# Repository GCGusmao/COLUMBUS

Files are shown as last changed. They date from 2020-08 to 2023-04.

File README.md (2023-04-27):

# COLUMBUS

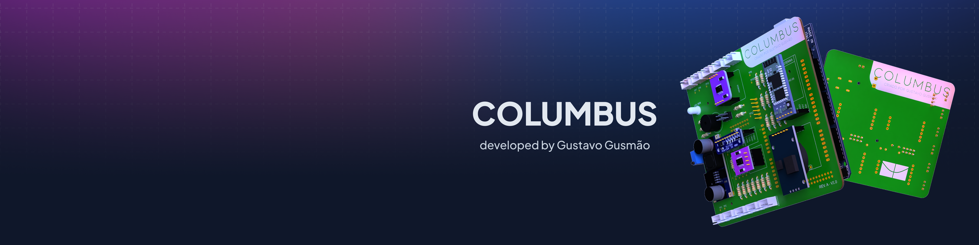
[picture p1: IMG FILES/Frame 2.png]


README ainda em construção.

Desenvolvimento de um sistema de monitoramento para veículos híbridos, baseado em microcontrolador Atmel AVR. Foi desenvolvida a solução completa de hardware, software e soluções mecânicas.

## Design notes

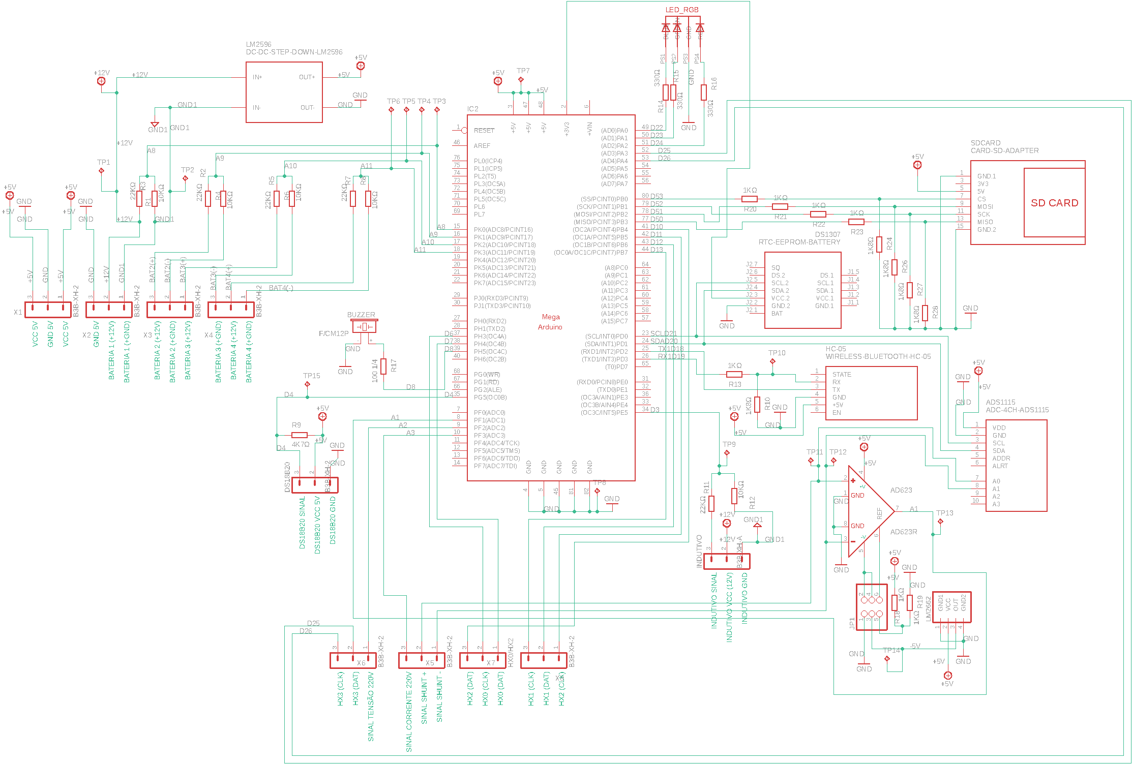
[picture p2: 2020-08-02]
EAGLE FILES/TCC2/Diagrama1.png

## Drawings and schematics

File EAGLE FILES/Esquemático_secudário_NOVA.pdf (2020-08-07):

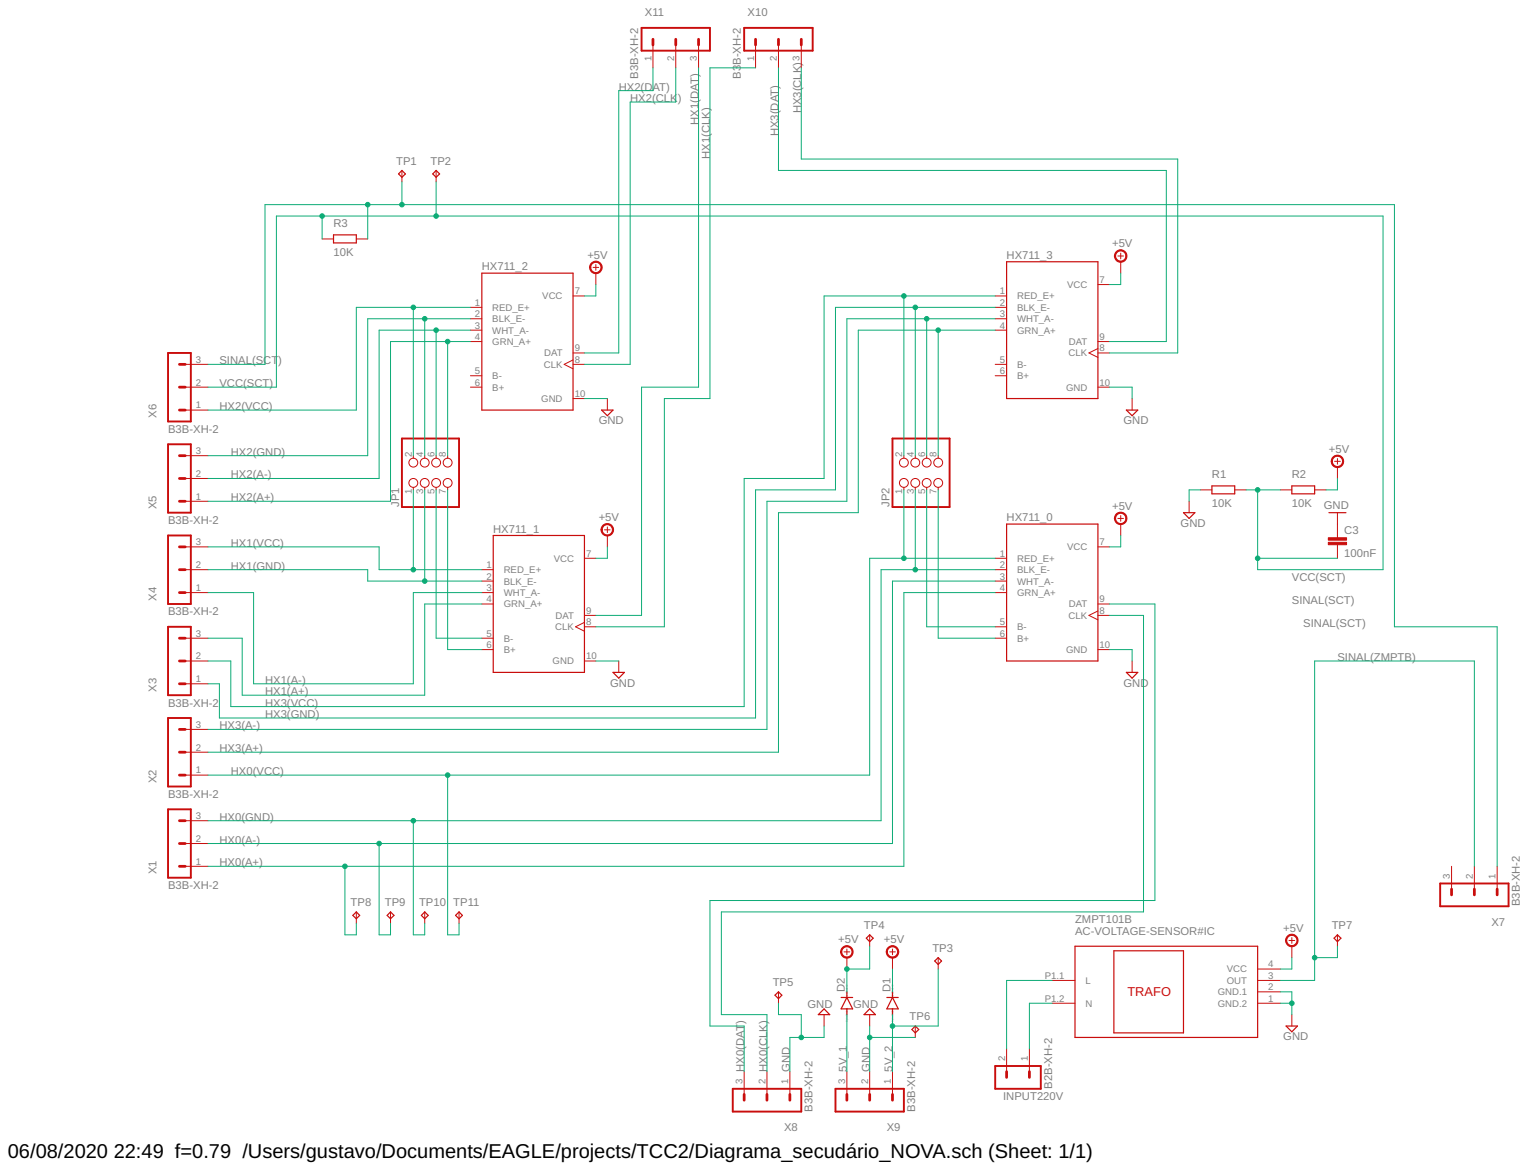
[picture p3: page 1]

VCC(SCT)
SINAL(SCT)

ZMPT101B
AC-VOLTAGE-SENSOR#IC

N | TRAFO | VCC | 4 OUT
P1.2 | L P1.1 | | | 2 GND.2

06/08/2020 22:49 f=0.79 /Users/gustavo/Documents/EAGLE/projects/TCC2/Diagrama_secudário_NOVA.sch (Sheet: 1/1)

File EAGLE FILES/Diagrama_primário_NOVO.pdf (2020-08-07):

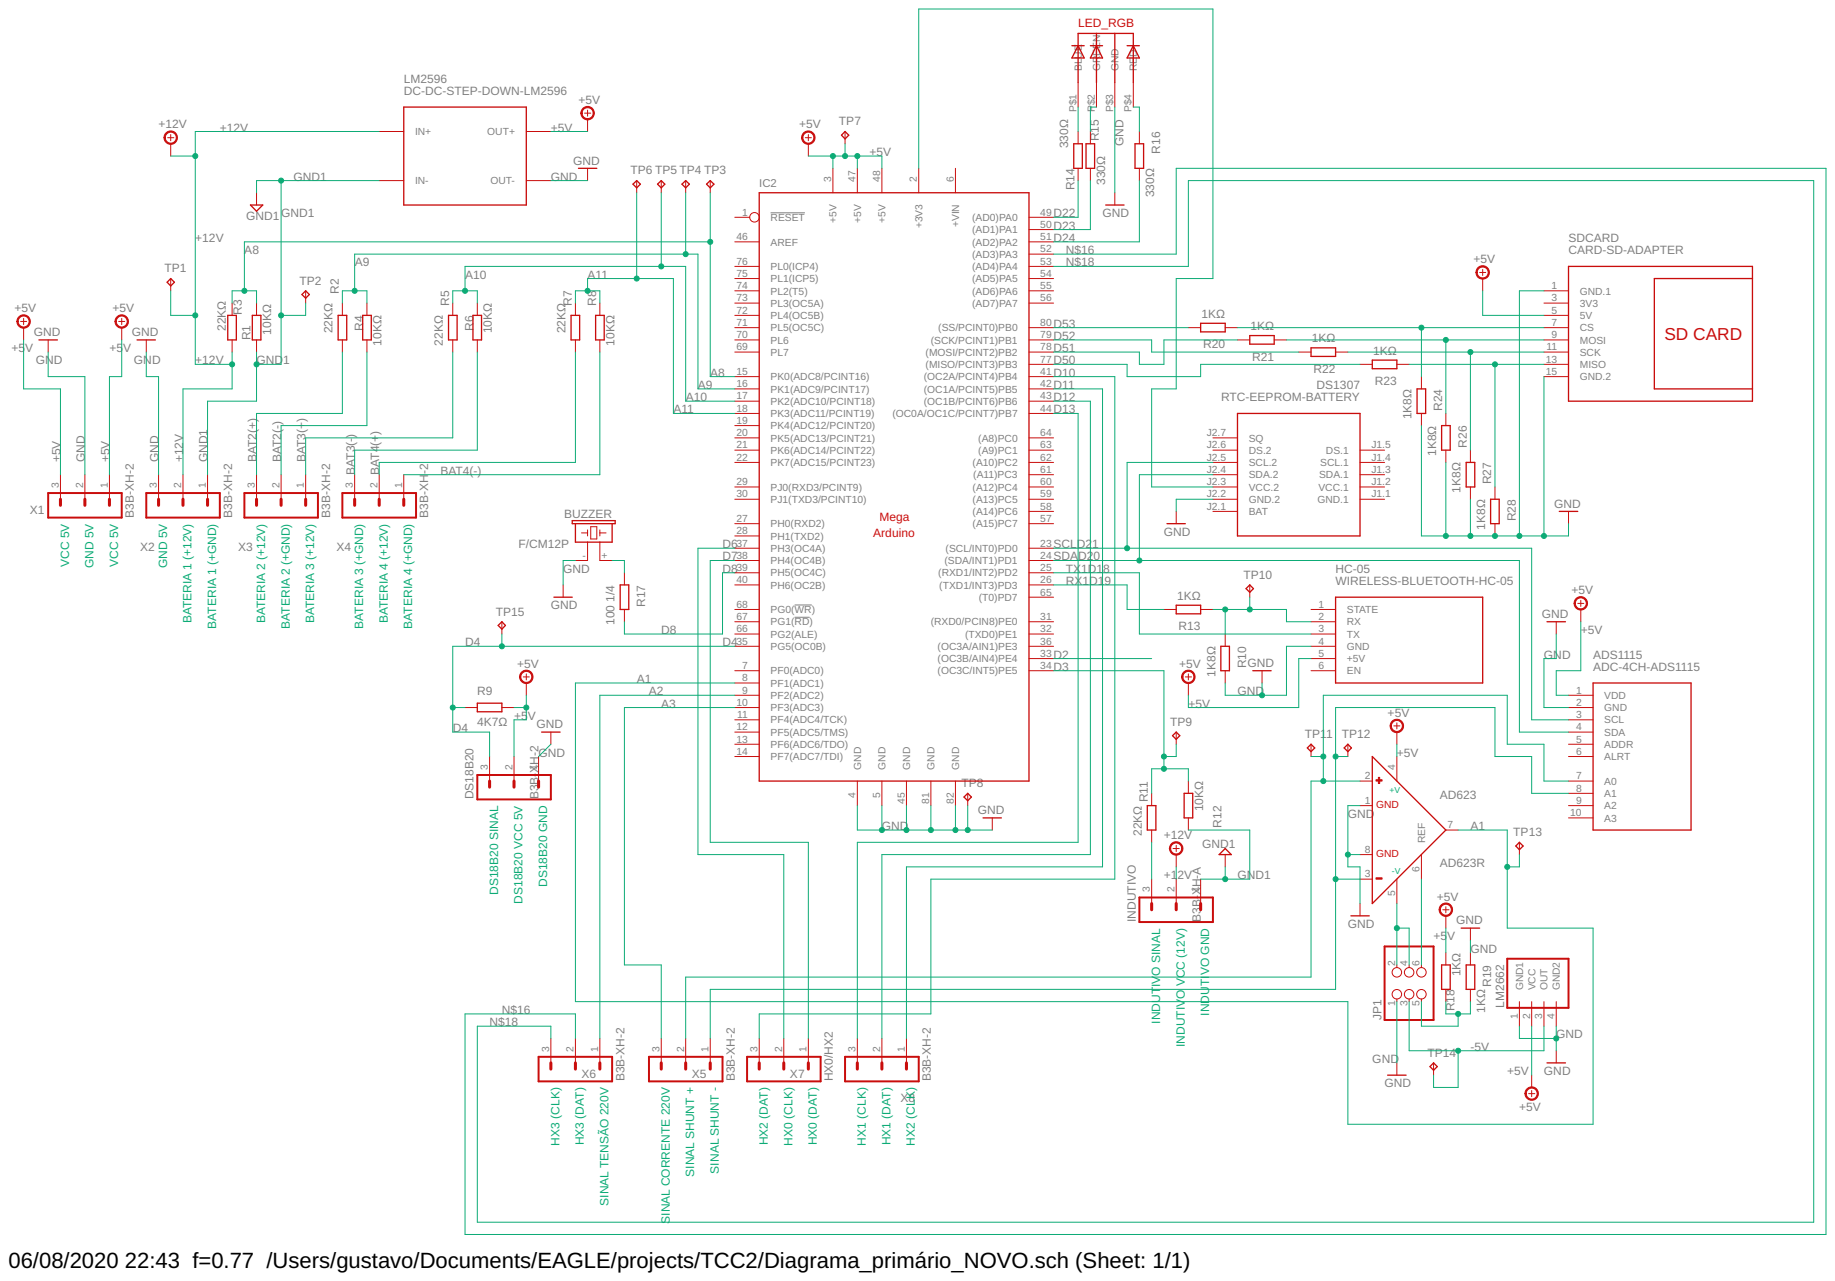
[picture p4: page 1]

DC-DC-STEP-DOWN-LM2596

SDCARD CARD-SD-ADAPTER

BATERIA 1 (+12V) BATERIA 1 (+GND) BATERIA 2 (+12V) BATERIA 2 (+GND) BATERIA 3 (+12V) BATERIA 3 (+GND) BATERIA 4 (+12V) BATERIA 4 (+GND)

24
25 RX1D19 TX1D18 | | HC-05

SINAL SHUNT + SINAL SHUNT -

HX2 (DAT) HX0 (CLK) HX0 (DAT) HX1 (CLK) HX1 (DAT) HX2 (CLK)

06/08/2020 22:43 f=0.77 /Users/gustavo/Documents/EAGLE/projects/TCC2/Diagrama_primário_NOVO.sch (Sheet: 1/1)

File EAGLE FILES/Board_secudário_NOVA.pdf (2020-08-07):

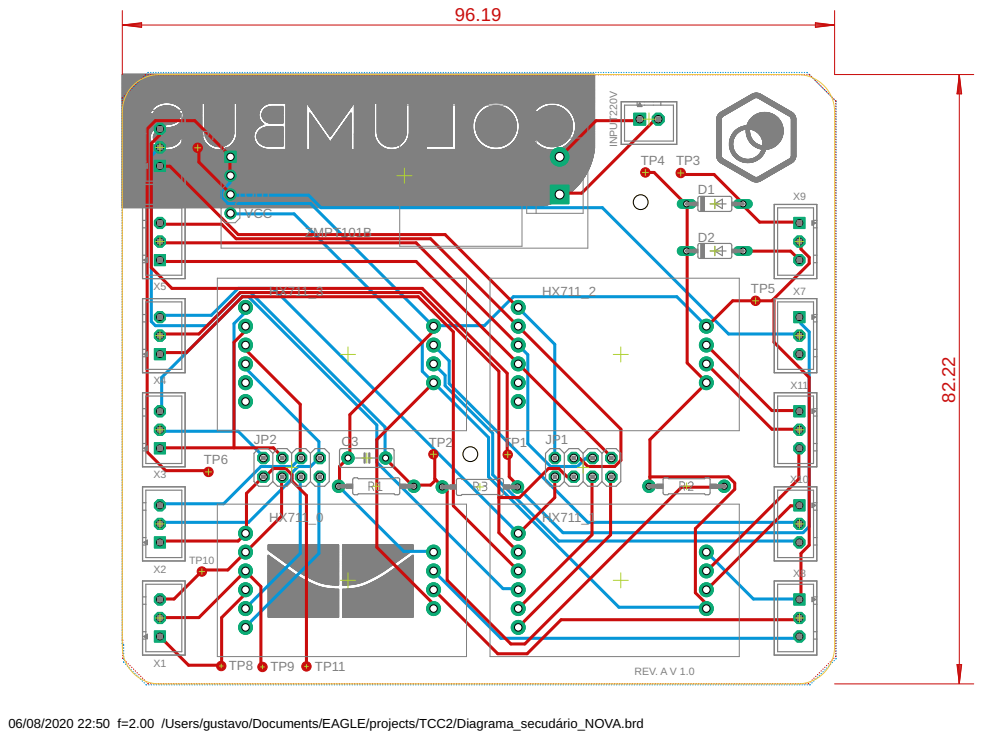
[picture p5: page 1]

06/08/2020 22:50 f=2.00 /Users/gustavo/Documents/EAGLE/projects/TCC2/Diagrama_secudário_NOVA.brd

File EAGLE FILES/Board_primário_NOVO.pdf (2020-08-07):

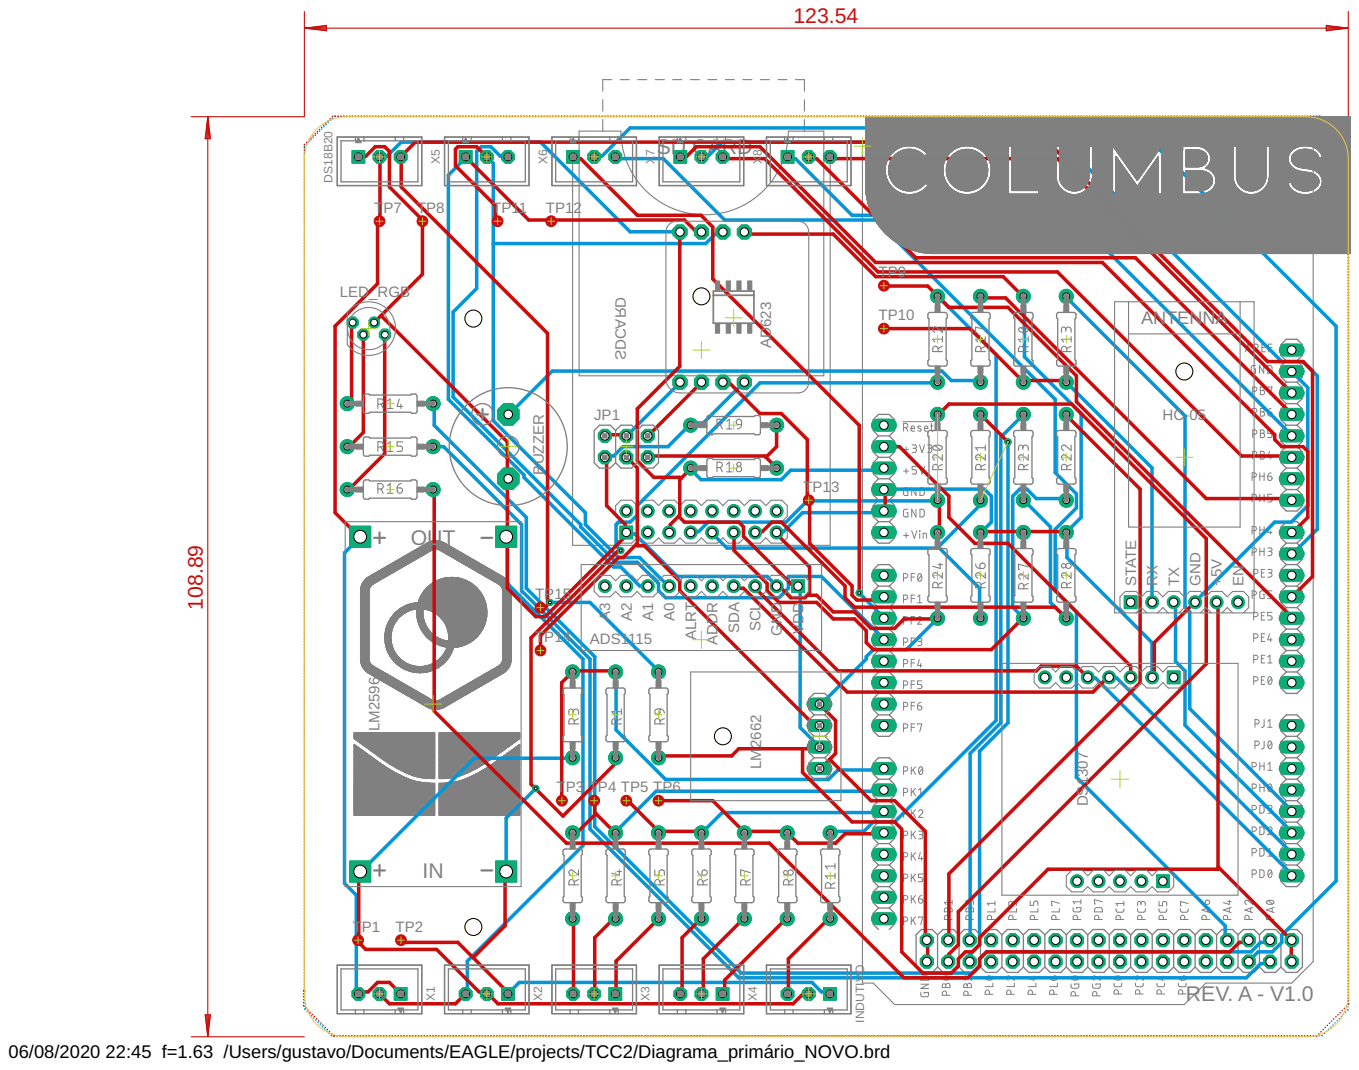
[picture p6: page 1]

06/08/2020 22:45 f=1.63 /Users/gustavo/Documents/EAGLE/projects/TCC2/Diagrama_primário_NOVO.brd

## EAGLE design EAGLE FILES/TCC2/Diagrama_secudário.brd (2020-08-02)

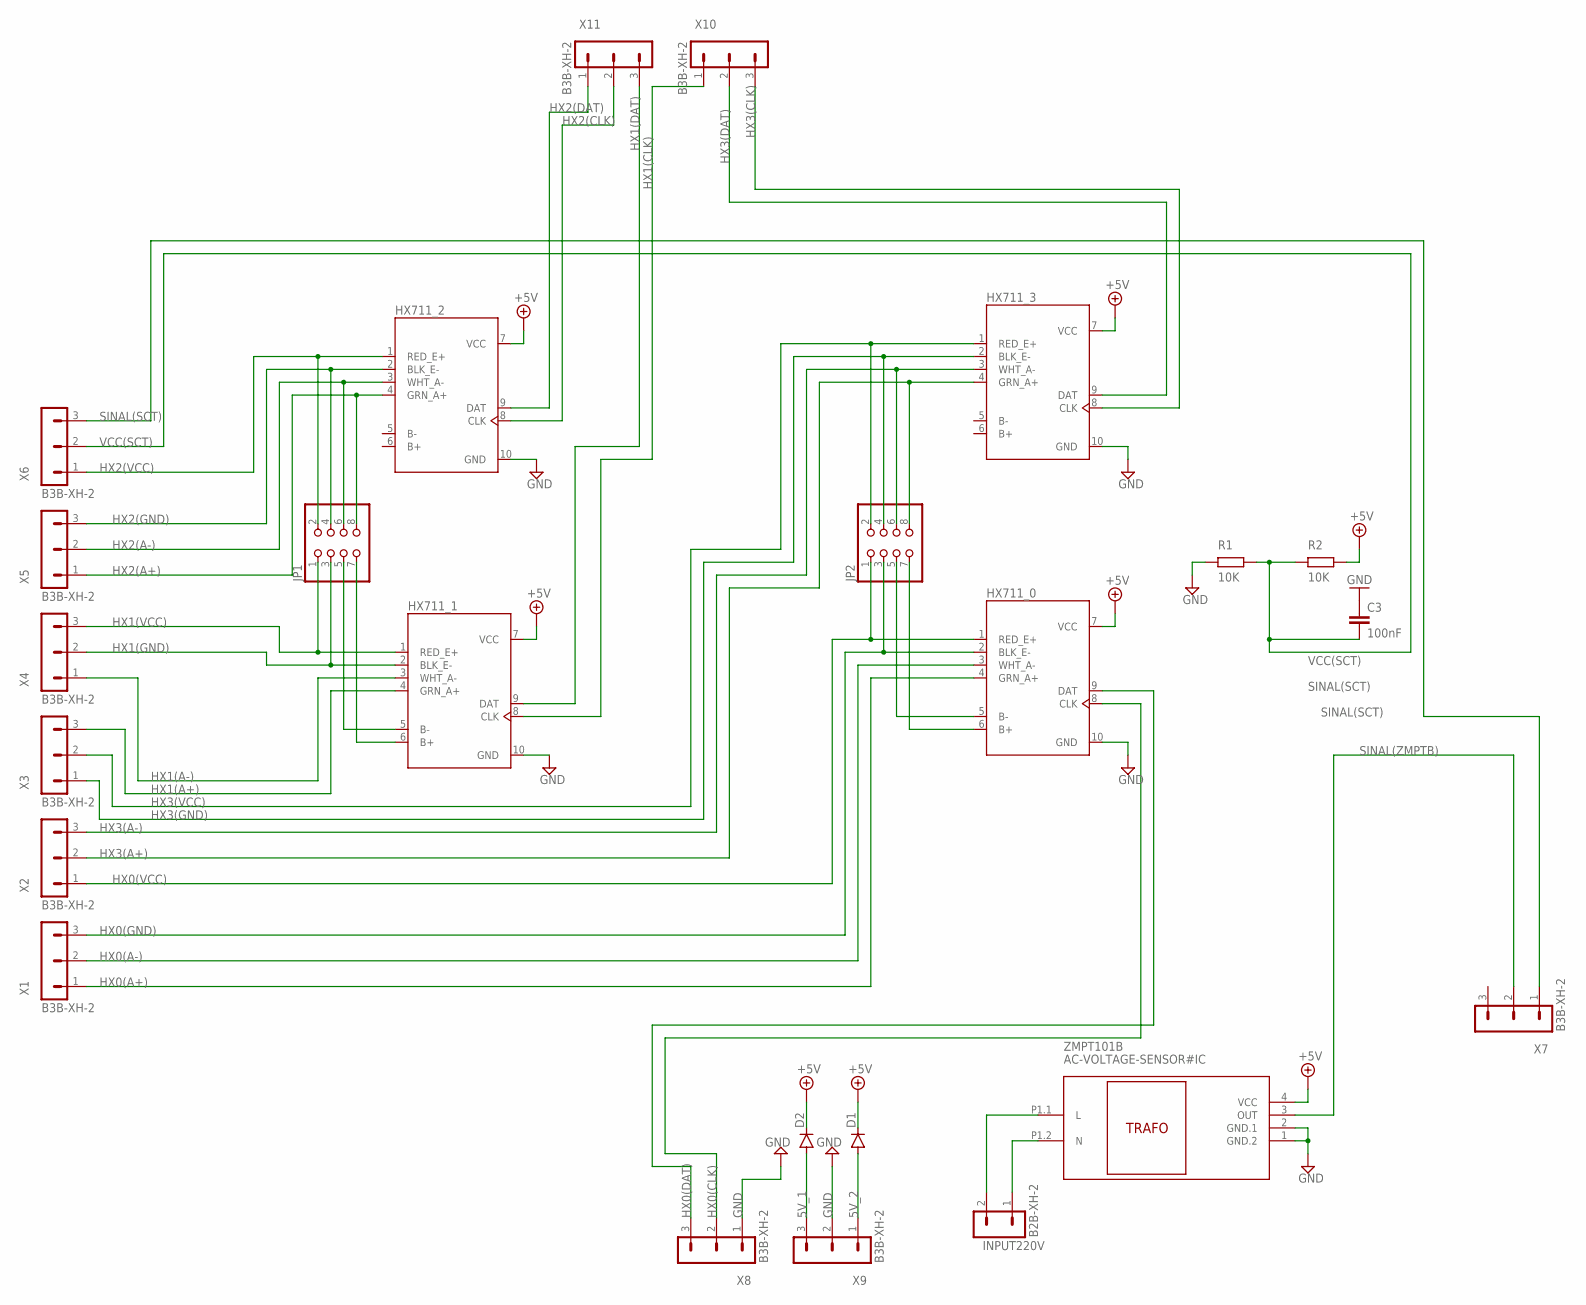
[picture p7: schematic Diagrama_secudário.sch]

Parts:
C3: 100nF; C050-025X075
D1: 1N4148DO35-7; DO35-7
D2: 1; DO35-7
HX711_0, HX711_1, HX711_2, HX711_3: HX711MODULO
INPUT220V: B2B-XH-2; B2B-XH-A
JP1, JP2: PINHD-2X4; 2X04
R1, R2: 10K; 1/4W-0.41K
X1, X2, X3, X4, X5, X6, X7, X8, X9, X10, X11: B3B-XH-2; B3B-XH-A
ZMPT101B: AC-VOLTAGE-SENSOR#IC

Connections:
5V_1: D2.A, X9.3
5V_2: D1.A, X9.1
+5V: D1.C, D2.C, HX711_0.7 (VCC), HX711_1.7 (VCC), HX711_2.7 (VCC), HX711_3.7 (VCC), R2.2, ZMPT101B.4 (VCC)
GND: C3.1, HX711_0.10 (GND), HX711_1.10 (GND), HX711_2.10 (GND), HX711_3.10 (GND), R1.1, X8.1, X9.2, ZMPT101B.1 (GND.2), ZMPT101B.2 (GND.1)
HX0(A+): HX711_0.4 (GRN_A+), X1.1
HX0(A-): HX711_0.3 (WHT_A-), X1.2
HX0(B+): HX711_0.6 (B+), JP2.7
HX0(B-): HX711_0.5 (B-), JP2.5
HX0(CLK): HX711_0.8 (CLK), X8.2
HX0(DAT): HX711_0.9 (DAT), X8.3
HX0(GND): HX711_0.2 (BLK_E-), JP2.3, X1.3
HX0(VCC): HX711_0.1 (RED_E+), JP2.1, X2.1
HX1(A+): HX711_1.4 (GRN_A+), X3.3
HX1(A-): HX711_1.3 (WHT_A-), X4.1
HX1(B+): HX711_1.6 (B+), JP1.7
HX1(B-): HX711_1.5 (B-), JP1.5
HX1(CLK): HX711_1.8 (CLK), X10.1
HX1(DAT): HX711_1.9 (DAT), X11.3
HX1(GND): HX711_1.2 (BLK_E-), JP1.3, X4.2
HX1(VCC): HX711_1.1 (RED_E+), JP1.1, X4.3
HX2(A+): HX711_2.4 (GRN_A+), JP1.8, X5.1
HX2(A-): HX711_2.3 (WHT_A-), JP1.6, X5.2
HX2(CLK): HX711_2.8 (CLK), X11.2
HX2(DAT): HX711_2.9 (DAT), X11.1
HX2(GND): HX711_2.2 (BLK_E-), JP1.4, X5.3
HX2(VCC): HX711_2.1 (RED_E+), JP1.2, X6.1
HX3(A+): HX711_3.4 (GRN_A+), JP2.8, X2.2
HX3(A-): HX711_3.3 (WHT_A-), JP2.6, X2.3
HX3(CLK): HX711_3.8 (CLK), X10.3
HX3(DAT): HX711_3.9 (DAT), X10.2
HX3(GND): HX711_3.2 (BLK_E-), JP2.4, X3.1
HX3(VCC): HX711_3.1 (RED_E+), JP2.2, X3.2
unnamed: INPUT220V.1, ZMPT101B.P1.2 (N)
unnamed: INPUT220V.2, ZMPT101B.P1.1 (L)
SINAL(SCT): X6.3, X7.1
SINAL(ZMPTB): X7.2, ZMPT101B.3 (OUT)
VCC(SCT): C3.2, R1.2, R2.1, X6.2

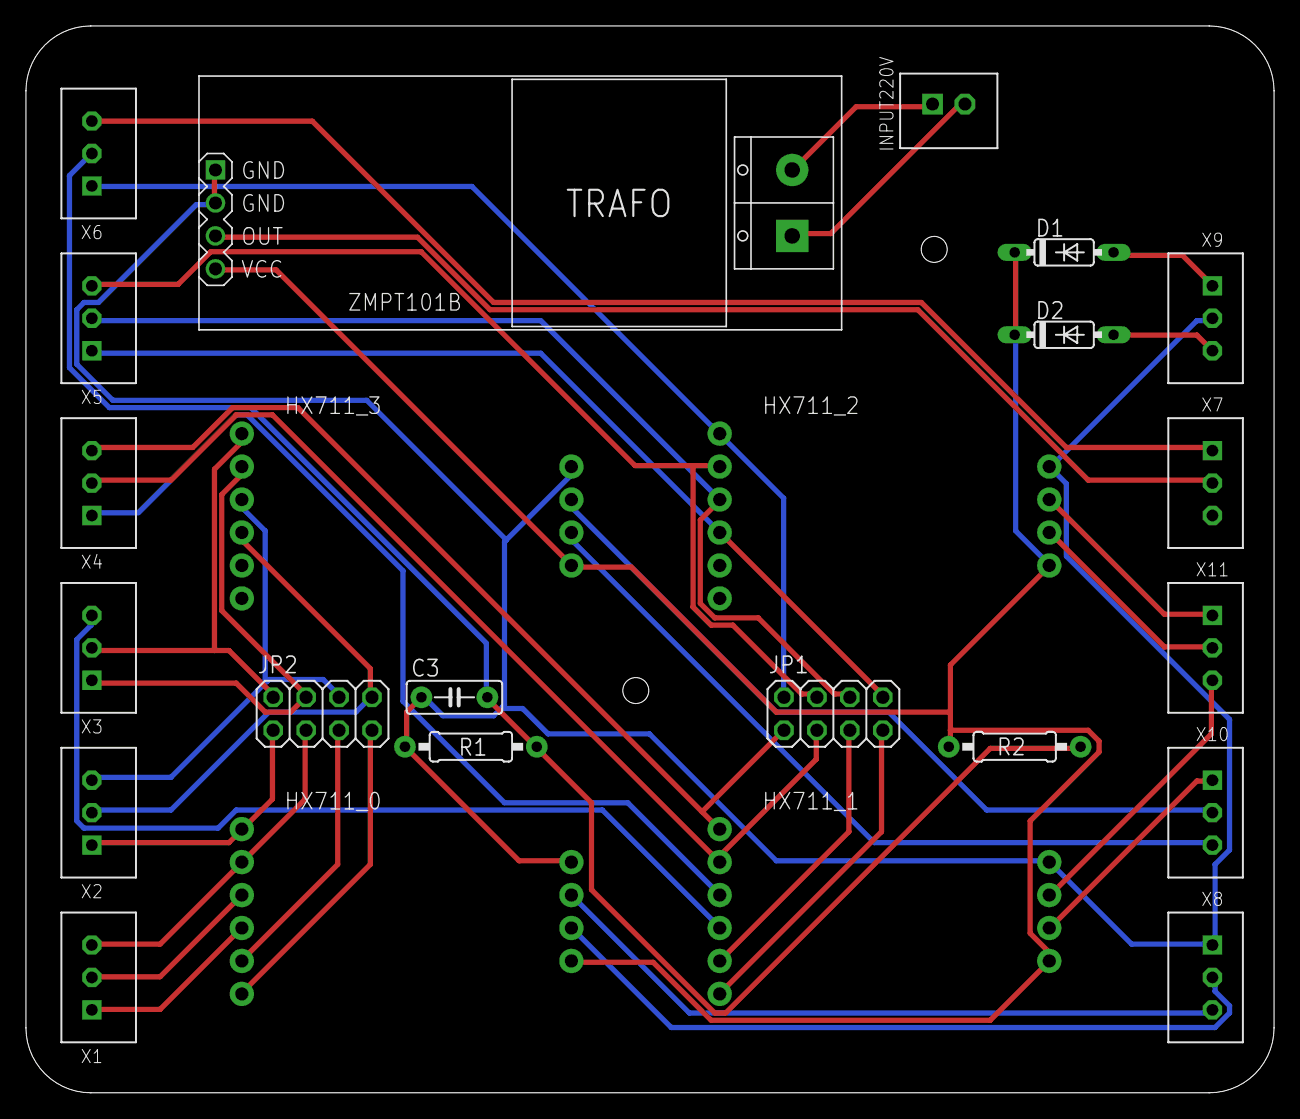
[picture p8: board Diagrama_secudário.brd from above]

Board: 2 copper layers, 96.2 x 82.2 mm, 24 parts (0 on the bottom side), 37 nets.

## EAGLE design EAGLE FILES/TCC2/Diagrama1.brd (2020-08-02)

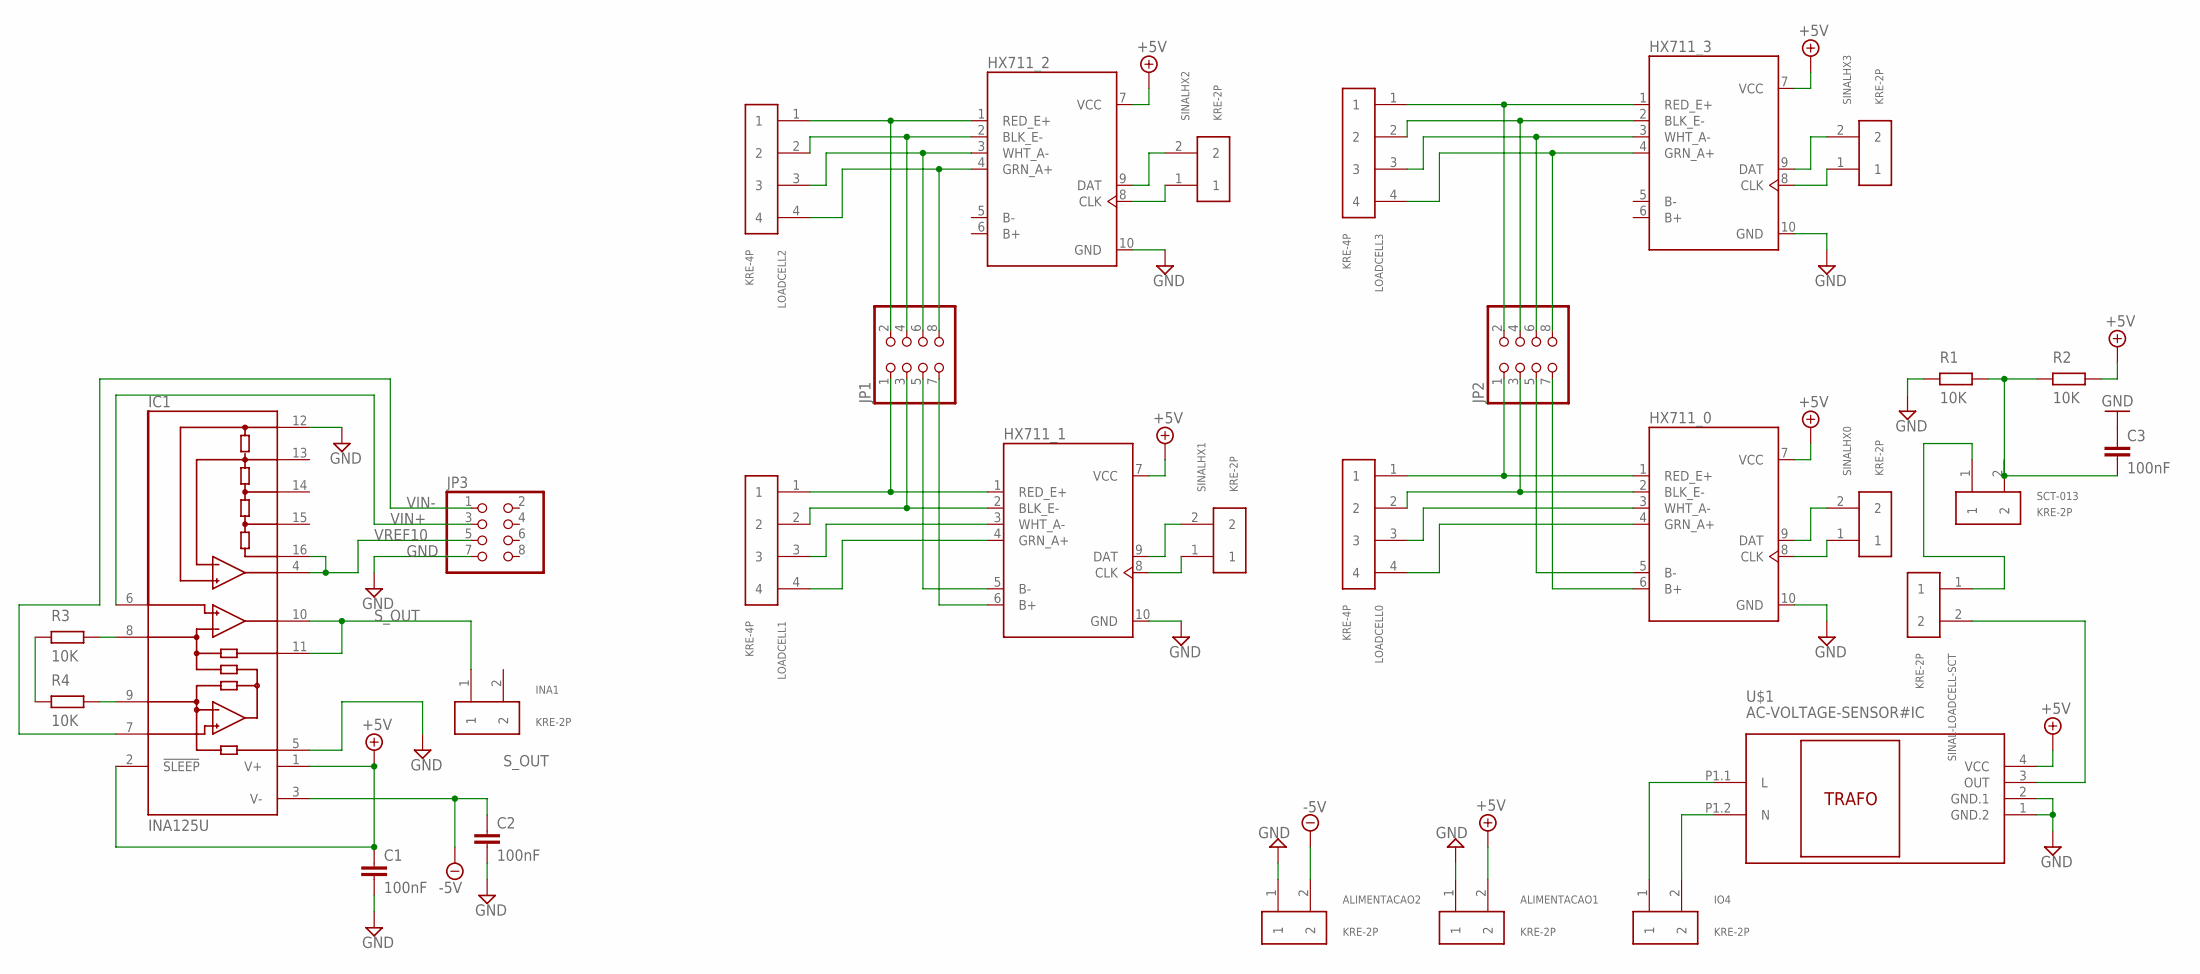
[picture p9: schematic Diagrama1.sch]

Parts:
ALIMENTACAO1, ALIMENTACAO2: KRE-2P
C1, C2, C3: 100nF; C050-025X075
HX711_0, HX711_1, HX711_2, HX711_3: HX711MODULO
IC1: INA125U; SO16-1
INA1: KRE-2P
IO4: KRE-2P
JP1, JP2, JP3: PINHD-2X4; 2X04
LOADCELL0, LOADCELL1, LOADCELL2, LOADCELL3: KRE-4P
R1, R2, R3, R4: 10K; 1/4W-0.41K
SCT-013: KRE-2P
SINAL-LOADCELL-SCT: KRE-2P
SINALHX0, SINALHX1, SINALHX2, SINALHX3: KRE-2P
U$1: AC-VOLTAGE-SENSOR#IC

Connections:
+5V: ALIMENTACAO1.2, C1.1, HX711_0.7 (VCC), HX711_1.7 (VCC), HX711_2.7 (VCC), HX711_3.7 (VCC), IC1.1 (V+), IC1.2 (!SLEEP), R2.2, U$1.4 (VCC)
-5V: ALIMENTACAO2.2, C2.1, IC1.3 (V-)
GND: ALIMENTACAO1.1, ALIMENTACAO2.1, C1.2, C2.2, C3.1, HX711_0.10 (GND), HX711_1.10 (GND), HX711_2.10 (GND), HX711_3.10 (GND), IC1.5 (REF), IC1.12 (REFCOM), JP3.7, R1.1, U$1.1 (GND.2), U$1.2 (GND.1)
unnamed: IO4.2, U$1.P1.2 (N)
unnamed: IO4.1, U$1.P1.1 (L)
unnamed: HX711_0.1 (RED_E+), JP2.1, LOADCELL0.1
unnamed: HX711_0.4 (GRN_A+), LOADCELL0.4
unnamed: HX711_0.2 (BLK_E-), JP2.3, LOADCELL0.2
unnamed: HX711_1.1 (RED_E+), JP1.1, LOADCELL1.1
unnamed: HX711_0.3 (WHT_A-), LOADCELL0.3
unnamed: HX711_1.2 (BLK_E-), JP1.3, LOADCELL1.2
unnamed: HX711_1.3 (WHT_A-), LOADCELL1.3
unnamed: C3.2, R1.2, R2.1, SCT-013.2
unnamed: HX711_0.9 (DAT), SINALHX0.2
unnamed: HX711_0.8 (CLK), SINALHX0.1
unnamed: HX711_1.5 (B-), JP1.5
unnamed: HX711_1.4 (GRN_A+), LOADCELL1.4
unnamed: SINAL-LOADCELL-SCT.2, U$1.3 (OUT)
unnamed: HX711_1.9 (DAT), SINALHX1.2
unnamed: HX711_1.8 (CLK), SINALHX1.1
unnamed: HX711_2.1 (RED_E+), JP1.2, LOADCELL2.1
unnamed: HX711_2.2 (BLK_E-), JP1.4, LOADCELL2.2
unnamed: HX711_2.3 (WHT_A-), JP1.6, LOADCELL2.3
unnamed: HX711_2.4 (GRN_A+), JP1.8, LOADCELL2.4
unnamed: HX711_2.9 (DAT), SINALHX2.2
unnamed: HX711_2.8 (CLK), SINALHX2.1
unnamed: HX711_3.1 (RED_E+), JP2.2, LOADCELL3.1
unnamed: HX711_3.2 (BLK_E-), JP2.4, LOADCELL3.2
unnamed: HX711_3.3 (WHT_A-), JP2.6, LOADCELL3.3
unnamed: HX711_3.4 (GRN_A+), JP2.8, LOADCELL3.4
unnamed: HX711_3.9 (DAT), SINALHX3.2
unnamed: HX711_3.8 (CLK), SINALHX3.1
unnamed: SCT-013.1, SINAL-LOADCELL-SCT.1
unnamed: HX711_1.6 (B+), JP1.7
unnamed: HX711_0.5 (B-), JP2.5
unnamed: HX711_0.6 (B+), JP2.7
unnamed: R3.1, R4.1
unnamed: IC1.9 (RG), R4.2
unnamed: IC1.8 (RG), R3.2
S_OUT: IC1.10 (OUT), IC1.11 (SENSE), INA1.1
VIN+: IC1.6 (+IN), JP3.3
VIN-: IC1.7 (-IN), JP3.1
VREF10: IC1.4 (REFOUT), IC1.16 (REF10), JP3.5

Board: 2 copper layers, 30 parts (0 on the bottom side), 43 nets, no tracks yet.

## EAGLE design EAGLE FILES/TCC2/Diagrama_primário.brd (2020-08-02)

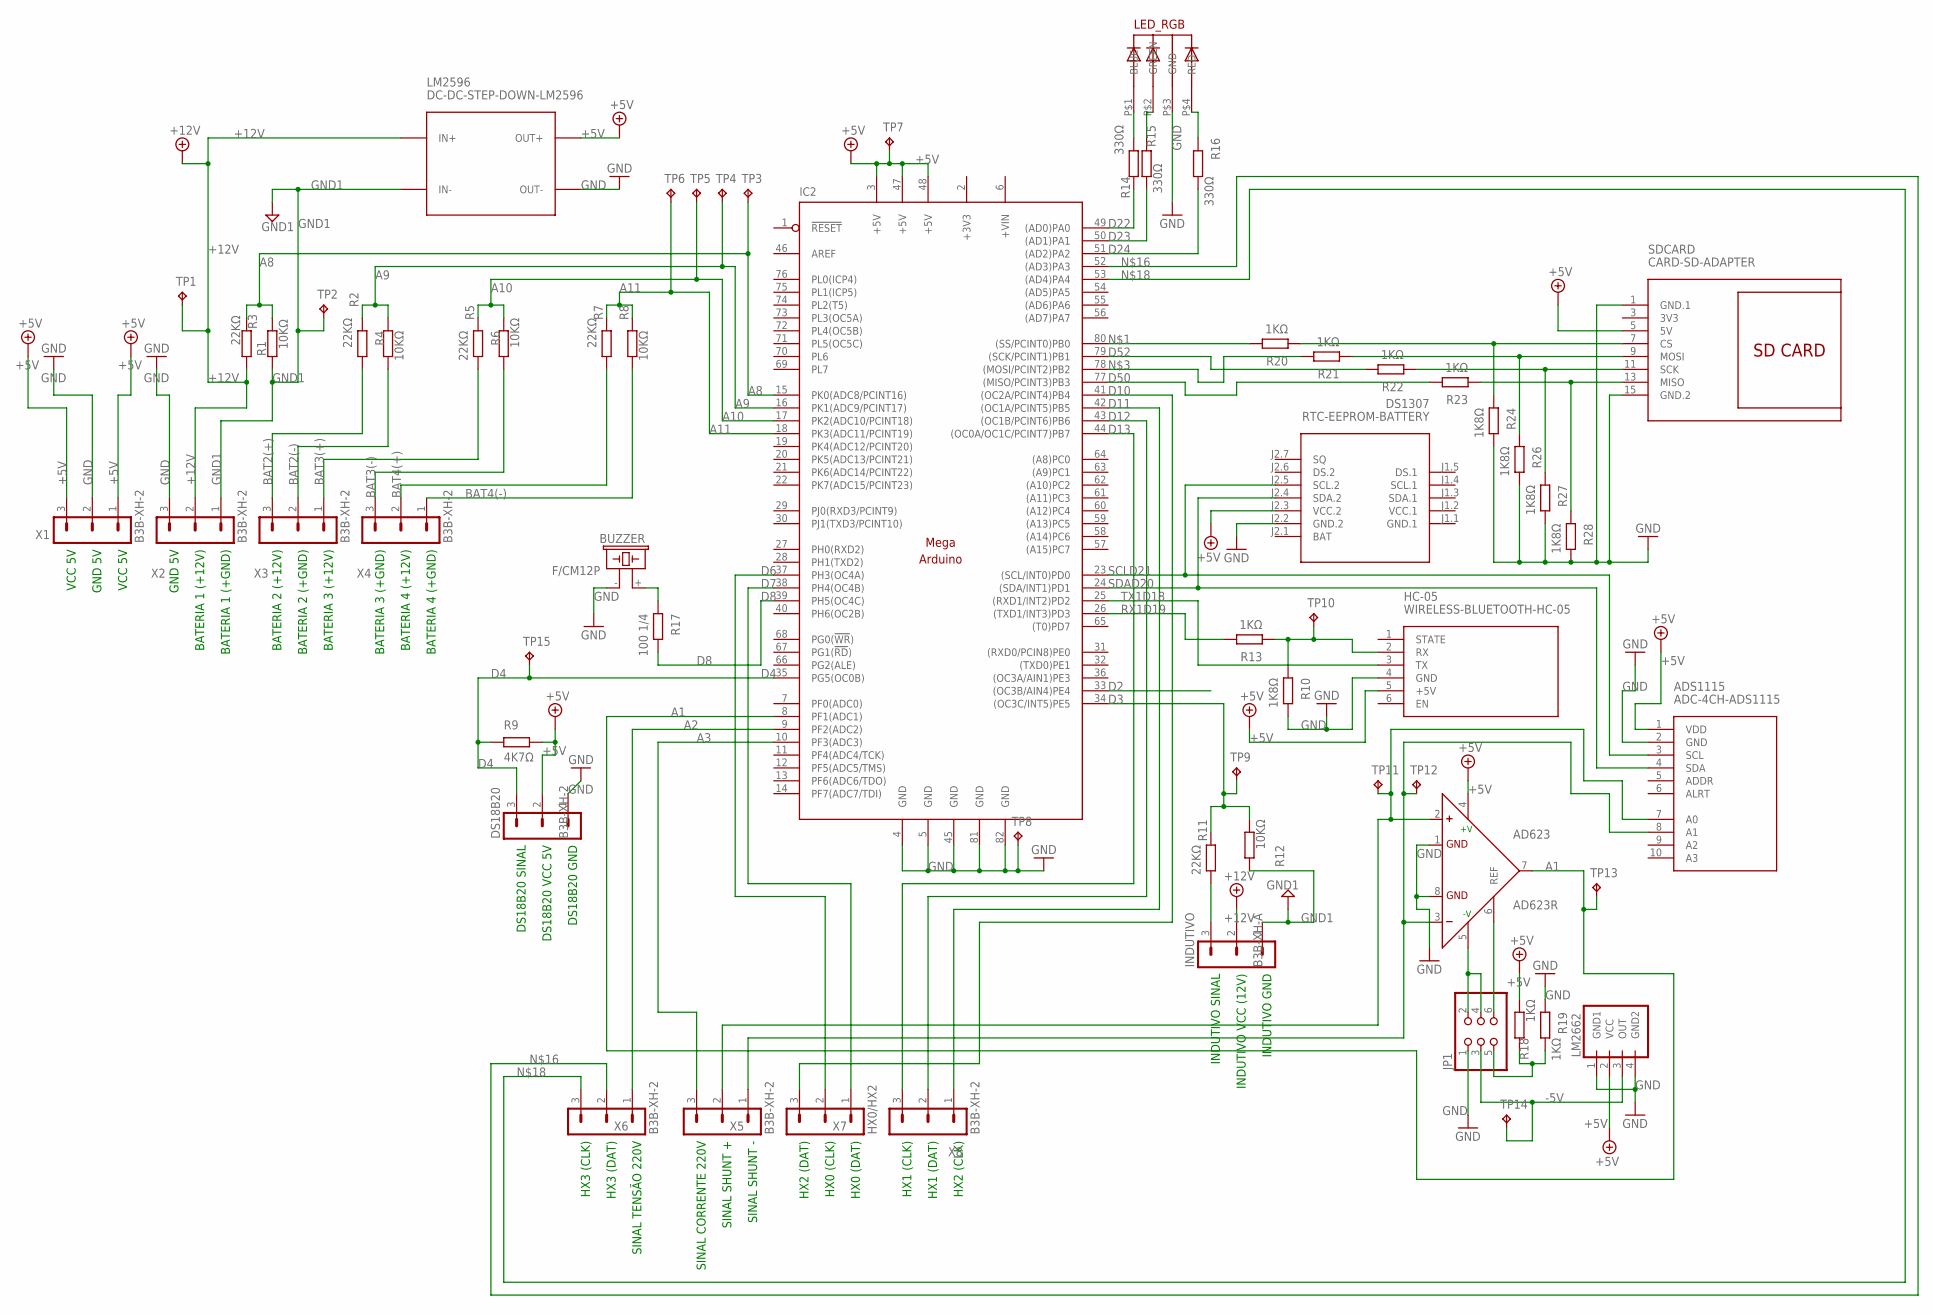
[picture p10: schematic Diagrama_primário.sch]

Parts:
AD623: AD623R; SO8
ADS1115: ADC-4CH-ADS1115
BUZZER: F/CM12P
DS18B20: B3B-XH-2; B3B-XH-A
DS1307: RTC-EEPROM-BATTERY
HC-05: WIRELESS-BLUETOOTH-HC-05
IC2: MEGAARDUINO_11; MEGA_ARDUINO_1
INDUTIVO: B3B-XH-A
JP1: PINHD-2X3; 2X03
LED_RGB: 5MMRGBLED; LED5MMRGB
LM2596: DC-DC-STEP-DOWN-LM2596
LM2662: LM2662
R1, R4, R6, R8, R12: 10KΩ; 1/4W-0.41K
R2, R3, R5, R7, R11: 22KΩ; 1/4W-0.41K
R9: 4K7Ω; 1/4W-0.41K
R10, R24, R26, R27, R28: 1K8Ω; 1/4W-0.41K
R13, R18, R19, R20, R21, R22, R23: 1KΩ; 1/4W-0.41K
R14, R15, R16: 330Ω; 1/4W-0.41K
R17: 100 1/4; 1/4W-0.41K
SDCARD: CARD-SD-ADAPTER
TP1, TP2, TP3, TP4, TP5, TP6, TP7, TP8, TP9, TP10, TP11, TP12, TP13, TP14, TP15: TPB1,27; B1,27
X1, X2, X3, X4, X5, X6, X8: B3B-XH-2; B3B-XH-A
X7: HX0/HX2; B3B-XH-A

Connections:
3V3: SDCARD.3 (3V3)
+3V3: IC2.2 (+3V3)
+5V: AD623.4 (+V), ADS1115.1 (VDD), DS18B20.2, DS1307.J2.3 (VCC.2), HC-05.5 (+5V), IC2.3 (+5V), IC2.47 (+5V), IC2.48 (+5V), LM2596.OUT+, LM2662.2 (VCC), R9.2, R18.1, SDCARD.5 (5V), TP7.TP, X1.1, X1.3
+12V: INDUTIVO.2, LM2596.IN+, R3.2, TP1.TP, X2.2
+VIN: IC2.6 (+VIN)
-5V: JP1.3, LM2662.3 (OUT), TP14.TP
A1: AD623.7 (OUT), IC2.8 (PF1(ADC1)), TP13.TP
A2: IC2.9 (PF2(ADC2)), X6.1
A3: IC2.10 (PF3(ADC3)), X5.3
A8: IC2.15 (PK0(ADC8/PCINT16)), R1.1, R3.1, TP3.TP
A9: IC2.16 (PK1(ADC9/PCINT17)), R2.1, R4.1, TP4.TP
A10: IC2.17 (PK2(ADC10/PCINT18)), R5.1, R6.1, TP5.TP
A11: IC2.18 (PK3(ADC11/PCINT19)), R7.1, R8.1, TP6.TP
BAT2(+): R2.2, X3.3
BAT2(-): R4.2, X3.2
BAT3(+): R5.2, X3.1
BAT3(-): R6.2, X4.3
BAT4(+): R7.2, X4.2
BAT4(-): R8.2, X4.1
D2: IC2.33 ((OC3B/AIN4)PE4)
D3: IC2.34 ((OC3C/INT5)PE5), R11.1, R12.1, TP9.TP
D4: DS18B20.3, IC2.35 (PG5(OC0B)), R9.1, TP15.TP
D6: IC2.37 (PH3(OC4A)), X7.2
D7: IC2.38 (PH4(OC4B)), X7.1
D8: IC2.39 (PH5(OC4C)), R17.2
D10: IC2.41 ((OC2A/PCINT4)PB4), X7.3
D11: IC2.42 ((OC1A/PCINT5)PB5), X8.1
D12: IC2.43 ((OC1B/PCINT6)PB6), X8.2
D13: IC2.44 ((OC0A/OC1C/PCINT7)PB7), X8.3
D22: IC2.49 ((AD0)PA0), R14.2
D23: IC2.50 ((AD1)PA1), R15.2
D24: IC2.51 ((AD2)PA2), R16.2
D50: IC2.77 ((MISO/PCINT3)PB3), R23.2
D51: R21.1, R26.1, SDCARD.9 (MOSI)
D52: IC2.79 ((SCK/PCINT1)PB1), R22.2
D53: R20.1, R24.1, SDCARD.7 (CS)
GND: AD623.1 (RG), AD623.8 (RG), ADS1115.2 (GND), BUZZER.- (2), DS18B20.1, DS1307.J2.2 (GND.2), HC-05.4 (GND), IC2.4 (GND), IC2.5 (GND), IC2.45 (GND), IC2.81 (GND), IC2.82 (GND), JP1.1, LED_RGB.P$3 (GND), LM2596.OUT-, LM2662.1 (GND1), LM2662.4 (GND2), R10.2, R19.1, R24.2, R26.2, R27.2, R28.2, SDCARD.1 (GND.1), SDCARD.15 (GND.2), TP8.TP, X1.2, X2.3
GND1: INDUTIVO.1, LM2596.IN-, R1.2, R12.2, TP2.TP, X2.1
GND.1: DS1307.J1.1 (GND.1)
unnamed: IC2.80 ((SS/PCINT0)PB0), R20.2
unnamed: INDUTIVO.3, R11.2
unnamed: IC2.78 ((MOSI/PCINT2)PB2), R21.2
unnamed: HC-05.2 (RX), R10.1, R13.1, TP10.TP
unnamed: LED_RGB.P$1 (BLUE), R14.1
unnamed: LED_RGB.P$2 (GREEN), R15.1
unnamed: LED_RGB.P$4 (RED), R16.1
unnamed: R22.1, R27.1, SDCARD.11 (SCK)
unnamed: R23.1, R28.1, SDCARD.13 (MISO)
unnamed: IC2.52 ((AD3)PA3), X6.2
unnamed: BUZZER.+ (1), R17.1
unnamed: IC2.53 ((AD4)PA4), X6.3
unnamed: AD623.3 (-), ADS1115.8 (A1), TP12.TP, X5.1
unnamed: AD623.2 (+), ADS1115.7 (A0), TP11.TP, X5.2
unnamed: AD623.5 (-V), JP1.2, JP1.4
unnamed: AD623.6 (REF), JP1.6
RX1D19: IC2.26 ((TXD1/INT3)PD3), R13.2
SCLD21: ADS1115.3 (SCL), DS1307.J2.5 (SCL.2), IC2.23 ((SCL/INT0)PD0)
SDAD20: ADS1115.4 (SDA), DS1307.J2.4 (SDA.2), IC2.24 ((SDA/INT1)PD1)
TX1D18: HC-05.3 (TX), IC2.25 ((RXD1/INT2)PD2)
VCC1: JP1.5, R18.2, R19.2
VCC.1: DS1307.J1.2 (VCC.1)

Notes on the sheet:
SINAL CORRENTE 220V
SINAL SHUNT +
SINAL SHUNT -
HX3 (CLK)
SINAL TENSÃO 220V
HX2 (DAT)
HX0 (CLK)
HX0 (DAT)
HX1 (CLK)
HX1 (DAT)
HX2 (CLK)
INDUTIVO SINAL
INDUTIVO VCC (12V)
INDUTIVO GND
DS18B20 SINAL
DS18B20 VCC 5V
DS18B20 GND
VCC 5V
GND 5V
BATERIA 1 (+12V)
BATERIA 1 (+GND)
BATERIA 2 (+12V)
BATERIA 2 (+GND)
BATERIA 3 (+12V)
BATERIA 3 (+GND)
BATERIA 4 (+12V)
BATERIA 4 (+GND)
HX3 (DAT)

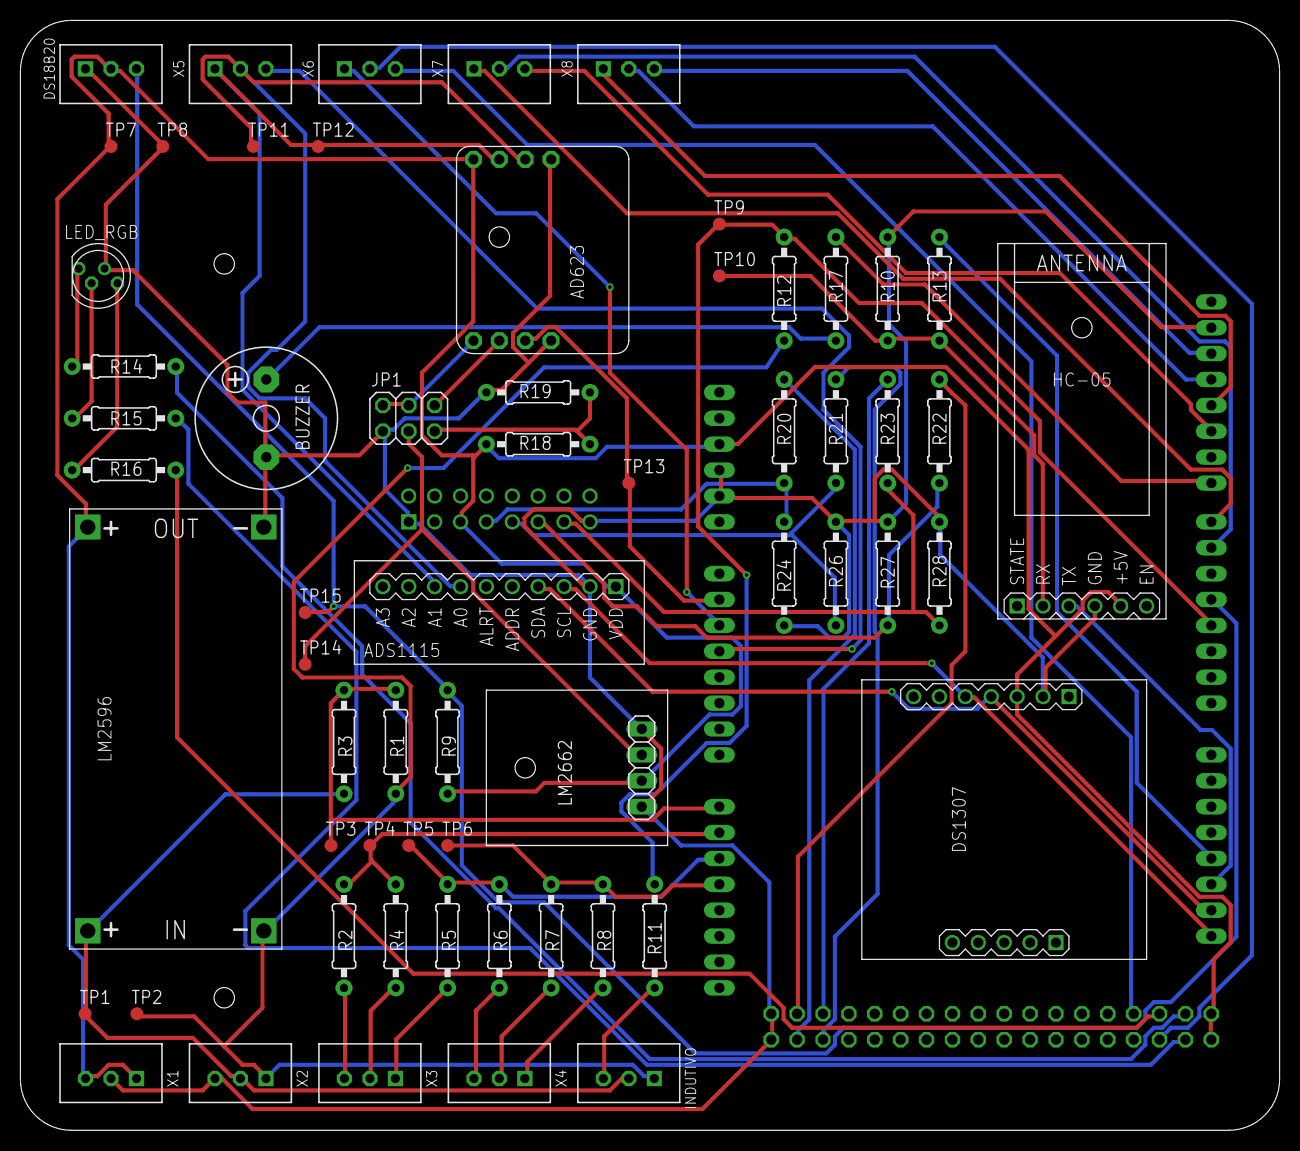
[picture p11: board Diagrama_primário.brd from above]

Board: 2 copper layers, 123.5 x 108.9 mm, 63 parts (0 on the bottom side), 55 nets.

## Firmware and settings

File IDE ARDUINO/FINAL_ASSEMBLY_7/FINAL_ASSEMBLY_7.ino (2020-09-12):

#include <SD.h>
#include <SPI.h>
#include "RTClib.h"
#include "EmonLib.h"
#include <Wire.h>
#include <OneWire.h>
#include <DallasTemperature.h>
#include <Adafruit_ADS1015.h>
#include "HX711.h"                    // Biblioteca HX711 

//define programa do SD CARD
File myFile;

//Módulo RTC DS3231 ligado as portas 20 e 21 do Arduino
RTC_DS3231 rtc;

char daysOfTheWeek[7][12] = {"Sunday", "Monday", "Tuesday", "Wednesday", "Thursday", "Friday", "Saturday"};

//VALOR DE CALIBRAÇÃO PARA SENSOR DE TENSÃO (DEVE SER AJUSTADO EM PARALELO COM UM MULTÍMETRO)
#define VOLT_CAL 400

//VALOR DE AMOSTRAS PARA MÉDIA MÓVEL LEITOR DE TENSÃO 12V
#define AMOSTRAS 10

//Define o pino do sinal digital do DS18B20.
#define ONE_WIRE_BUS 4

#define DOUT_1  7                      // HX711 DATA OUT = pino A0 do Arduino 
#define CLK_1  6                       // HX711 SCK IN = pino A1 do Arduino 

#define DOUT_0  25                      // HX711 DATA OUT = pino A0 do Arduino 
#define CLK_0  26                       // HX711 SCK IN = pino A1 do Arduino 

//Variáveis do LED RGB da placa principal
#define RED_PIN 24
#define GREEN_PIN 23
#define BLUE_PIN 22

//Variáveis relacionadas com o sensor de rotação indutivo
#define pino_D0 3

//Buzzer!

#define NOTE_G4  392
#define NOTE_C5  523

#define REST      0

//Variáveis Buzzer

// change this to make the song slower or faster
int tempo = 85;

// change this to whichever pin you want to use
int buzzer = 8;

int melody[] = {NOTE_C5,8, NOTE_G4,8};

//Mais funções do Buzzer!

int notes = sizeof(melody) / sizeof(melody[0]) / 2;

// this calculates the duration of a whole note in ms
int wholenote = (60000 * 4) / tempo;

int divider = 0, noteDuration = 0;


//Pino analógico conectado ao SCT-013
int pinSCT = A3;

//Cria uma instância para SCT013
EnergyMonitor SCT013;

//CRIA UMA INSTÂNCIA para ZMPT101b (substituir ZMPT por zmpt)
EnergyMonitor ZMPT;

//Módulo ADS1115 com 16-bits
Adafruit_ADS1115 ads;

HX711 balanca_0;                        // define instancia balança HX711
HX711 balanca_1;                        // define instancia balança HX711


// Setup a oneWire instance to communicate with any OneWire device
OneWire oneWire(ONE_WIRE_BUS);

// Pass oneWire reference to DallasTemperature library
DallasTemperature sensors(&oneWire);

// Addresses of 4 DS18B20s
uint8_t sensorX0[8] = { 0x28, 0xAA, 0xB8, 0x5A, 0x4D, 0x14, 0x01, 0x97 };
uint8_t sensorX8[8] = { 0x28, 0xAA, 0x74, 0x9E, 0x4A, 0x14, 0x01, 0xD9 };
uint8_t sensorX4[8] = { 0x28, 0xAA, 0x19, 0xF2, 0x54, 0x14, 0x01, 0x18 };
uint8_t sensorX2[8] = { 0x28, 0xAA, 0x27, 0x04, 0x4D, 0x14, 0x01, 0x82 };

//Variáveis do sensor DS18B20
int deviceCount = 0;
float tempC;
float b1temp;
float b2temp;
float b3temp;
float b4temp;

//Variáveis relacionadas com o sensor de ZMPT101b e SCT013
double tensao250v;
double potencia250v;
double corrente250v;

//Variáveis relacionadas com o sensor de rotação indutivo
int rpm;
int veloc;
volatile byte pulsos;
unsigned long timeold;

//IMPLEMENTACAO EXPERIMENTAL DE VELOCIDADE PELO PULSEIN

double veloc_ON;         //Variável que armazena a leitura INSTANTÂNEA do tempo de injeção.
double veloc_OFF;
int    veloc_PULSE; 

//EXCLUIR O CODIGO ACIMA CASO NAO SEJA UTILIZADO

//Define o número de sinais por volta
unsigned int pulsos_por_volta = 4;

//Pino CS do módulo SD CARD. Pin 53 para Mega / Pin 10 para UNO
int pinoSS = 53;

//Variáveis relacionadas a interface do serial
bool escolha0 = false;

bool escolha1 = false;

//Variável relacionada com o sensor de corrente SHUNT
float correnteLV;

float calibration_factor = 235533.00;     // fator de calibração aferido na Calibraçao

float massa_combustivel;

//Variáveis relacionadas ao medidor de tensão 12V das baterias
float b1tensao;
float b2tensao;
float b3tensao;
float b4tensao;
float btotaltensao;

float aRef = 5.00; //tensão de referência


// constants won't change. They're used here to set pin numbers:
const int buttonPin = 10;  // the number of the pushbutton pin

// variables will change:
int buttonState = 0;         // variable for reading the pushbutton status

bool startState = false; 


//FUNÇÃO LEITURA DE TENSÃO 12V
float lePorta(uint8_t portaAnalogica) {
  float total = 0;
  for (int i = 0; i < AMOSTRAS; i++) {
    total += 1.0 * analogRead(portaAnalogica);
    // delay(5);
  }
  return total / (float)AMOSTRAS;
}


void contador()
{
  //Incrementa contador do sensor de rotação
  pulsos++;
}

void LEDiniciar () {

  digitalWrite(RED_PIN, HIGH);
  digitalWrite(GREEN_PIN, HIGH);
  digitalWrite(BLUE_PIN, HIGH);
  delay(100);
  digitalWrite(RED_PIN, LOW);
  digitalWrite(GREEN_PIN, LOW);
  digitalWrite(BLUE_PIN, HIGH);
  delay(100);
  digitalWrite(RED_PIN, LOW);
  digitalWrite(GREEN_PIN, LOW);
  digitalWrite(BLUE_PIN, LOW);
  delay(100);

}

void LEDerrorON () {
  digitalWrite(RED_PIN, HIGH);
  digitalWrite(GREEN_PIN, LOW);
  digitalWrite(BLUE_PIN, LOW);
}

void LEDerrorOFF () {
  digitalWrite(RED_PIN, LOW);
  digitalWrite(GREEN_PIN, LOW);
  digitalWrite(BLUE_PIN, LOW);
}

void serial0() {

    if (buttonState == HIGH) {
  //COLOCAR AQUI OS SERIAIS DO MODO 1 DE APRESENTACAO DOS DADOS
  //============================================ RTC SERIAL====================================

  DateTime now = rtc.now();

  Serial.print(now.day(), DEC);
  Serial.print('/');
  Serial.print(now.month(), DEC);
  Serial.print('/');
  Serial.print(now.year(), DEC);
  //Serial.print(" (");
  //Serial.print(daysOfTheWeek[now.dayOfTheWeek()]);
  Serial.print(", ");
  Serial.print(now.hour(), DEC);
  Serial.print(':');
  Serial.print(now.minute(), DEC);
  Serial.print(':');
  Serial.print(now.second(), DEC);
  Serial.print(" || ");

  //============================================ ROTAÇÃO SERIAL ====================================

  //Mostra o valor de RPM no serial monitor
  Serial.print("Veloc = ");
  Serial.print(veloc, DEC);
  Serial.print(" || ");
   Serial.print("Veloc+PULSE = ");
  Serial.print(veloc_PULSE, DEC);
  Serial.print(" || ");

  //============================================ CORRENTE LV SERIAL ================================

  Serial.print("Corrente 48V = ");
  Serial.print(correnteLV);
  Serial.print(" || ");

    //=============================================== Tensão 12v ====================

  Serial.print("Tensao B1: ");
  Serial.print(b1tensao, 2);
  Serial.print ("V");
  Serial.print(" || ");

  Serial.print("Tensao B2: ");
  Serial.print(b2tensao, 2);
  Serial.print ("V");
  Serial.print(" || ");

  Serial.print("Tensao B3: ");
  Serial.print(b3tensao, 2);
  Serial.print ("V");
  Serial.print(" || ");

  Serial.print("Tensao B4: ");
  Serial.print(b4tensao, 2);
  Serial.print ("V");
  Serial.print(" || ");

    //============================================= DS18B20 ===================
/*
  Serial.print("Sensor 1: ");
  Serial.print(b1temp);
  Serial.print("C");
  Serial.print(" || ");

  Serial.print("Sensor 2: ");
  Serial.print(b2temp);
  Serial.print("C");
  Serial.println(" || ");

  Serial.print("Sensor 3: ");
  Serial.print(b3temp);
  Serial.print("C");
  Serial.print(" || ");

  Serial.print("Sensor 4: ");
  Serial.print(b4temp);
  Serial.print("C");
  Serial.print(" || ");


  //============================================= CORRENTE, TENSÃO E POTENCIA HV ===================

  Serial.print("Corrente 220V = ");
  Serial.print(corrente250v);
  Serial.print(" A");
  Serial.print(" || ");

  Serial.print("Potencia 220V = ");
  Serial.print(potencia250v);
  Serial.print(" W");
  Serial.print(" || ");

  Serial.print("Tensão 220V = ");
  Serial.print(tensao250v);
  Serial.print(" V");
  Serial.print(" || ");

  //================================================ MASSA COMBUSTIVEL =============================================

  Serial.print("Massa total: ");                            // imprime no monitor serial
  Serial.print(massa_combustivel, 2);              // imprime peso na balança com 2 casas decimais
  Serial.println(" kg");
*/
  //delay(100);
}
}

void serial1() {

    if (buttonState == HIGH) {
  //COLOCAR AQUI OS SERIAIS DO MODO 1 DE APRESENTACAO DOS DADOS
  //============================================ RTC SERIAL====================================

  DateTime now = rtc.now();

  Serial1.print(now.day(), DEC);
  Serial1.print('/');
  Serial1.print(now.month(), DEC);
  Serial1.print('/');
  Serial1.print(now.year(), DEC);
  //Serial.print(" (");
  //Serial.print(daysOfTheWeek[now.dayOfTheWeek()]);
  Serial1.print(", ");
  Serial1.print(now.hour(), DEC);
  Serial1.print(':');
  Serial1.print(now.minute(), DEC);
  Serial1.print(':');
  Serial1.print(now.second(), DEC);
  Serial1.print(" || ");

  //============================================ ROTAÇÃO SERIAL ====================================

  //Mostra o valor de RPM no serial monitor
  Serial1.print("Veloc = ");
  Serial1.print(veloc, DEC);
  Serial1.print(" || ");

  //============================================ CORRENTE LV SERIAL ================================

  Serial1.print("Corrente 48V = ");
  Serial1.print(correnteLV);
  Serial1.print(" || ");

    //=============================================== Tensão 12v ====================

  Serial1.print("Tensao B1: ");
  Serial1.print(b1tensao, 2);
  Serial1.print ("V");
  Serial1.print(" || ");

  Serial1.print("Tensao B2: ");
  Serial1.print(b2tensao, 2);
  Serial1.print ("V");
  Serial1.print(" || ");

  Serial1.print("Tensao B3: ");
  Serial1.print(b3tensao, 2);
  Serial1.print ("V");
  Serial1.print(" || ");

  Serial1.print("Tensao B4: ");
  Serial1.print(b4tensao, 2);
  Serial1.print ("V");
  Serial1.print(" || ");

    //============================================= DS18B20 ===================
/*
  Serial1.print("Sensor 1: ");
  Serial1.print(b1temp);
  Serial1.print("C");
  Serial1.print(" || ");

  Serial1.print("Sensor 2: ");
  Serial1.print(b2temp);
  Serial1.print("C");
  Serial1.print(" || ");

  Serial1.print("Sensor 3: ");
  Serial1.print(b3temp);
  Serial1.print("C");
  Serial1.print(" || ");

  Serial1.print("Sensor 4: ");
  Serial1.print(b4temp);
  Serial1.print("C");
  Serial1.print(" || ");
*/

  //============================================= CORRENTE, TENSÃO E POTENCIA HV ===================
/*
  Serial1.print("Corrente 220V = ");
  Serial1.print(corrente250v);
  Serial1.print(" A");
  Serial1.print(" || ");

  Serial1.print("Potencia 220V = ");
  Serial1.print(potencia250v);
  Serial1.print(" W");
  Serial1.print(" || ");

  Serial1.print("Tensão 220V = ");
  Serial1.print(tensao250v);
  Serial1.print(" V");
  Serial1.print(" || ");
*/
  //================================================ MASSA COMBUSTIVEL =============================================
/*
  Serial1.print("Massa total: ");                            // imprime no monitor serial
  Serial1.print(massa_combustivel, 2);              // imprime peso na balança com 3 casas decimais
  Serial1.println(" kg");
*/
  //delay(100);
}
}

void serialTASK () {

    if (buttonState == HIGH) {
  //=================== SERIAL ===========================
  // Função que solicita o usuário qual forma de apresentação dos dados ele deseja.
  //


  if (Serial1.available()) {
    if (Serial1.read() == '2') {                   // se pressionar 2
      escolha1 = true;
    }
    if (Serial1.read() == '1') {                  // se pressionar 1
      escolha1 = false;
    }
  }
  
  else if (Serial.available()) {
    if (Serial.read() == '2') {                  // se pressionar 2
      escolha0 = true;
    }
    if (Serial.read() == '1') {                  // se pressionar 1
      escolha0 = false;
    }
  }

   if (escolha1 == true)
  {
    serial1();            // Chama a função da escrita no monitor serial Bluetooth
  }
  else if (escolha0 == true)
  {
    serial0();            // Chama a função da escrita no monitor serial USB
  }

    // read the state of the pushbutton value:
  buttonState = digitalRead(buttonPin);


}
}

void gravacaoTask() {

    if (buttonState == HIGH) {
  //=================== SD CARD ===========================

 if (SD.exists("datalog2.csv")) { // Se o Arquivo abrir imprime:

  
  myFile = SD.open("datalog2.csv", FILE_WRITE); // Cria / Abre arquivo .txt



    digitalWrite(RED_PIN, LOW);
    digitalWrite(GREEN_PIN, HIGH);
    digitalWrite(BLUE_PIN, LOW);

    if (escolha0 == true || escolha1 == true)                  // se pressionar t ou T
    {
      Serial.println("Escrevendo no Arquivo .txt"); // Imprime na tela
    }


    DateTime now = rtc.now();

    myFile.print(now.day(), DEC);
    myFile.print('/');
    myFile.print(now.month(), DEC);
    myFile.print('/');
    myFile.print(now.year(), DEC);
    myFile.print(";");
    myFile.print(now.hour(), DEC);
    myFile.print(':');
    myFile.print(now.minute(), DEC);
    myFile.print(':');
    myFile.print(now.second(), DEC);
    myFile.print(";"); // Escreve no Arquivo

    
//========================== ROTAÇÃO ============================
    myFile.print(veloc); // Escreve no Arquivo
    myFile.print(";"); // Escreve no Arquivo
//========================== CORRENTE LV =========================
    myFile.print(correnteLV); // Escreve no Arquivo
    myFile.print(";"); // Escreve no Arquivo
//========================== TENSÃO LV ===========================
    myFile.print(b1tensao); // Escreve no Arquivo
    myFile.print(";"); // Escreve no Arquivo
    myFile.print(b2tensao); // Escreve no Arquivo
    myFile.print(";"); // Escreve no Arquivo
    myFile.print(b3tensao); // Escreve no Arquivo
    myFile.print(";"); // Escreve no Arquivo
    myFile.print(b4tensao); // Escreve no Arquivo
    myFile.print(";"); // Escreve no Arquivo
//========================== CORRENTE HV =========================
    myFile.print(corrente250v); // Escreve no Arquivo
    myFile.print(";"); // Escreve no Arquivo
//========================== TENSÃO HV =========================
    myFile.print(tensao250v); // Escreve no Arquivo
    myFile.print(";"); // Escreve no Arquivo
//========================== TEMPERATURA BATERIAS =================
    myFile.print(b1temp); // Escreve no Arquivo
    myFile.print(";"); // Escreve no Arquivo
    myFile.print(b2temp); // Escreve no Arquivo
    myFile.print(";"); // Escreve no Arquivo
    myFile.print(b3temp); // Escreve no Arquivo
    myFile.print(";"); // Escreve no Arquivo
    myFile.print(b4temp); // Escreve no Arquivo
    myFile.print(";"); // Escreve no Arquivo
//========================== MASSA COMBUSTIVEL =========================
    myFile.println(massa_combustivel); // Escreve no Arquivo
   // myFile.print(","); // Escreve no Arquivo

    digitalWrite(RED_PIN, LOW);
    digitalWrite(GREEN_PIN, LOW);
    digitalWrite(BLUE_PIN, LOW);

    myFile.close(); // Fecha o Arquivo após escrever

    if (escolha0 == true || escolha1 == true)                  // se pressionar t ou T
    {

      Serial.println("Terminado."); // Imprime na tela
      Serial.println(" ");

    }

    digitalWrite(RED_PIN, LOW);
    digitalWrite(GREEN_PIN, HIGH);
    digitalWrite(BLUE_PIN, LOW);


  }

  else {// Se o Arquivo não abrir

    LEDerrorON ();

    if (escolha0 == true || escolha1 == true)                  // se pressionar t ou T
    {

      Serial.println("Erro ao Abrir Arquivo .txt"); // Imprime na tela

    }
    
    delay(1000);

    LEDerrorOFF ();


  }

  /*myFile = SD.open("datalog.txt"); // Abre o Arquivo

    if (myFile) {
    Serial.println("Conteúdo do Arquivo:"); // Imprime na tela

    while (myFile.available()) { // Exibe o conteúdo do Arquivo
    Serial.write(myFile.read());
    }

    myFile.close(); // Fecha o Arquivo após ler
    }

    else {
    Serial.println("Erro ao Abrir Arquivo .txt"); // Imprime na tela
    }
  */
}
}

void aquisicao1TASK() {

    if (buttonState == HIGH) {

//================================== ROTAÇÃO =======================================

  //Atualiza contador a cada segundo
  if (millis() - timeold >= 500)
  {
    //Desabilita interrupcao durante o calculo
    detachInterrupt(1);
    rpm = (60 * 1000 / pulsos_por_volta ) / (millis() - timeold) * pulsos;
    timeold = millis();
    pulsos = 0;
    //Habilita interrupcao
    attachInterrupt(1, contador, FALLING);
  }

  veloc_ON = pulseIn(1, HIGH);
  veloc_OFF = pulseIn(1, LOW);
  
  veloc_PULSE = ((1/((veloc_ON + veloc_OFF)/2000))*750);
    //veloc = ((1/((veloc_ON)/2000))*860) / 2;

//==================================================================================
//**********************************************************************************
//================================== SHUNT =========================================

  int16_t results;

  results = ads.readADC_Differential_0_1();


  correnteLV = ((float)results * 256.0) / 32768.0;//100mv shunt
  correnteLV = correnteLV * 1.333; //uncomment for 75mv shunt *JOGAR ESSES VALORES PARA O TASK DE CALCULO POSTERIORMENTE
  //amps = amps * 2; //uncomment for 50mv shunt

//==================================================================================
//**********************************************************************************
//================================== TENSÃO 12V ====================================

  b1tensao = (lePorta(A8) * aRef) / 1024.0;
  b2tensao = (lePorta(A9) * aRef) / 1024.0;
  b3tensao = (lePorta(A10) * aRef) / 1024.0;
  b4tensao = (lePorta(A11) * aRef) / 1024.0;

//==================================================================================
//**********************************************************************************
//================================== CORRENTE 220V =================================

  corrente250v = SCT013.calcIrms(1380);   // Calcula o valor da Corrente

//==================================================================================
//**********************************************************************************
//================================== TENSÃO 220V ===================================

  ZMPT.calcVI(10, 100); //FUNÇÃO DE CÁLCULO (20 SEMICICLOS, TEMPO LIMITE PARA FAZER A MEDIÇÃO)

  tensao250v = ZMPT.Vrms; //VARIÁVEL RECEBE O VALOR DE TENSÃO RMS OBTIDO

//==================================================================================

}
}


void aquisicao2TASK() {

    if (buttonState == HIGH) {

//================================== TEMPERATURA ===================================

  sensors.requestTemperatures();

  b1temp = sensors.getTempC(sensorX0);
  b2temp = sensors.getTempC(sensorX2);
  b3temp = sensors.getTempC(sensorX4);
  b4temp = sensors.getTempC(sensorX8);

//==================================================================================
//**********************************************************************************
//================================== CÉLULA DE CARGA ===============================

  //Serial.print("Peso 0: ");                            // imprime no monitor serial
  //Serial.print(balanca_0.get_units(), 2);              // imprime peso na balança com 3 casas decimais
  //Serial.print(" kg");                             // imprime no monitor serial
  //delay(500) ;                                       // atraso de 0,5 segundos

  //  Serial.print(" || Peso 1: ");                            // imprime no monitor serial
  //Serial.print(balanca_1.get_units(), 2);              // imprime peso na balança com 3 casas decimais
  //Serial.print(" kg");                             // imprime no monitor serial
  //delay(500) ; 

  if(rpm == 0){
  massa_combustivel = balanca_0.get_units() + balanca_1.get_units();
  }

//==================================================================================
    }
}

void operacoesTASK(){

    if (buttonState == HIGH) {

  b4tensao = (b4tensao * 9.95) - (b3tensao * 7.52);  //fator de calibração para os divisores de tensão.
  b3tensao = (b3tensao * 7.52) - (b2tensao * 4.95);  //fator de calibração para os divisores de tensão.
  b2tensao = (b2tensao * 4.95) - (b1tensao * 2.985);  //fator de calibração para os divisores de tensão.
  b1tensao = (b1tensao * 2.985);            //fator de calibração para os divisores de tensão.

  btotaltensao = b1tensao + b2tensao + b3tensao + b4tensao;

    veloc = 3.1416 * ((0.4572*rpm)/30) * 3.6;

    potencia250v = corrente250v * tensao250v;          // Calcula o valor da Potencia Instantanea
  
}
}

void powerTASK(){

  // read the state of the pushbutton value:
  buttonState = digitalRead(buttonPin);

  // check if the pushbutton is pressed. If it is, the buttonState is HIGH:
  if (buttonState == HIGH) {
    // turn LED on:
    if(startState == true){
      
    setup();
    startState = false;
    }
    
  } else {
    // turn LED off:
    startState = true;
    LEDerrorOFF ();
    escolha1 = false;
    escolha0 = false;

        delay(1000);
        
  }
  
}


void setup() {
  // put your setup code here, to run once:
  Serial.begin(9600);
  Serial1.begin(9600);


      if (buttonState == HIGH) {

  Serial.println("Iniciando o sistema..."); // Imprime na tela
  Serial1.println("Iniciando o sistema..."); // Imprime na tela

  // Declara pinoSS do SD CARD como saída
  pinMode(pinoSS, OUTPUT);
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
void loop() {

  aquisicao1TASK();
  aquisicao2TASK();
  operacoesTASK();
  gravacaoTask();
  serialTASK();
  powerTASK();

}

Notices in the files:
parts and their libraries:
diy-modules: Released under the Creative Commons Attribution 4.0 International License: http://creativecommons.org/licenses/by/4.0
